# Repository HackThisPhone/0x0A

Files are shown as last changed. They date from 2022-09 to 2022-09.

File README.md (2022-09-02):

# 0x0A
The 0x0A Smartphone is an open-source, open-hardware smartphone. Repairable, customizable, and fully yours, the 0x0A phone gives the power back to you! 

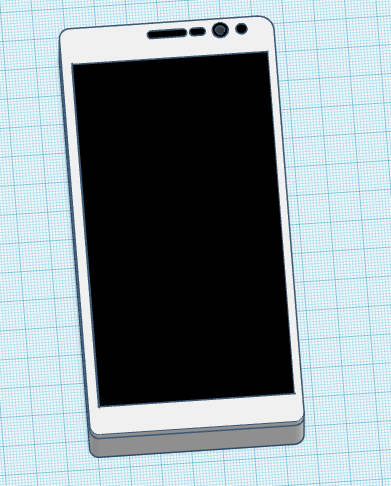
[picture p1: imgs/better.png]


## Features:

- Qualcomm Octa-Core ARM Cortex A-53 64-bit CPU @ 1.8GHz (2x quad-core with 512KB L2 cache)
- Adreno 506 GPU
- 16GB eMMC + 2GB LPDDR3
- 8,000mAh LiPo battery
- HD 720x1280 LCD with 16.7M color depth
- 10MP front & rear cameras
- 5G/4G/LTE/WCDMA
- WiFi 802.11a/b/g/n/ac
- Bluetooth 4.2/3.0/2.1
- GPS/BeiDou/GLONASS
- USB-C 3.0
- Dual SIM Standby
- 3D Printed Modular Case Design
- Full Schematics, BOM, & Supplier Info (self-serve on github)
- Android 9/10 Support
- Linux Support Planned (alternative operating systems welcomed here)

### Supported Carriers:

- North America    
  - Verizon
  - AT&T
  - T-Mobile
  - Sprint

Estimated BOM Cost: <$300
MSRP: $750

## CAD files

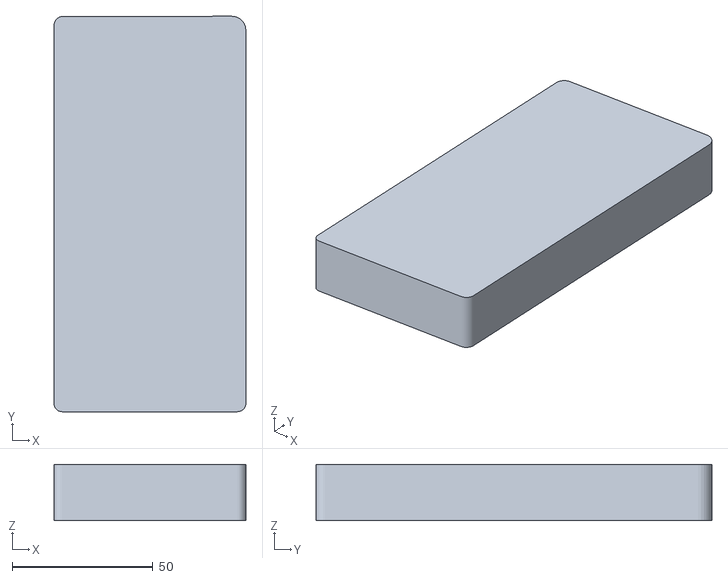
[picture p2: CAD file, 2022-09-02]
src/models/body.obj
68.3 x 140.7 x 20.0

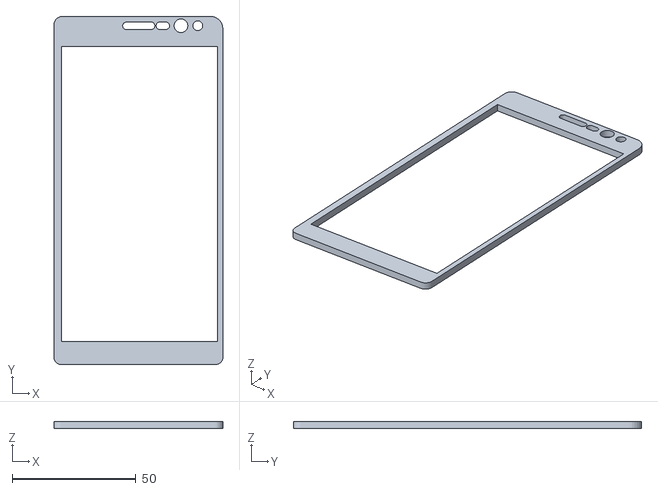
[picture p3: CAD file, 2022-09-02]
src/models/screen.obj
68.3 x 140.7 x 2.87

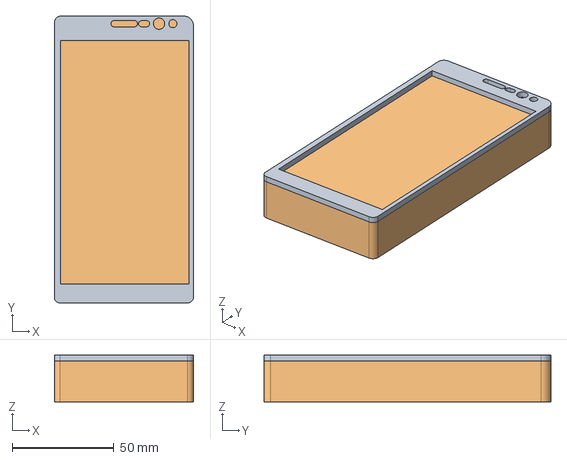
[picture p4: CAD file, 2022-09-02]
src/models/phone.FCStd
68.3 x 140.7 x 22.9 mm

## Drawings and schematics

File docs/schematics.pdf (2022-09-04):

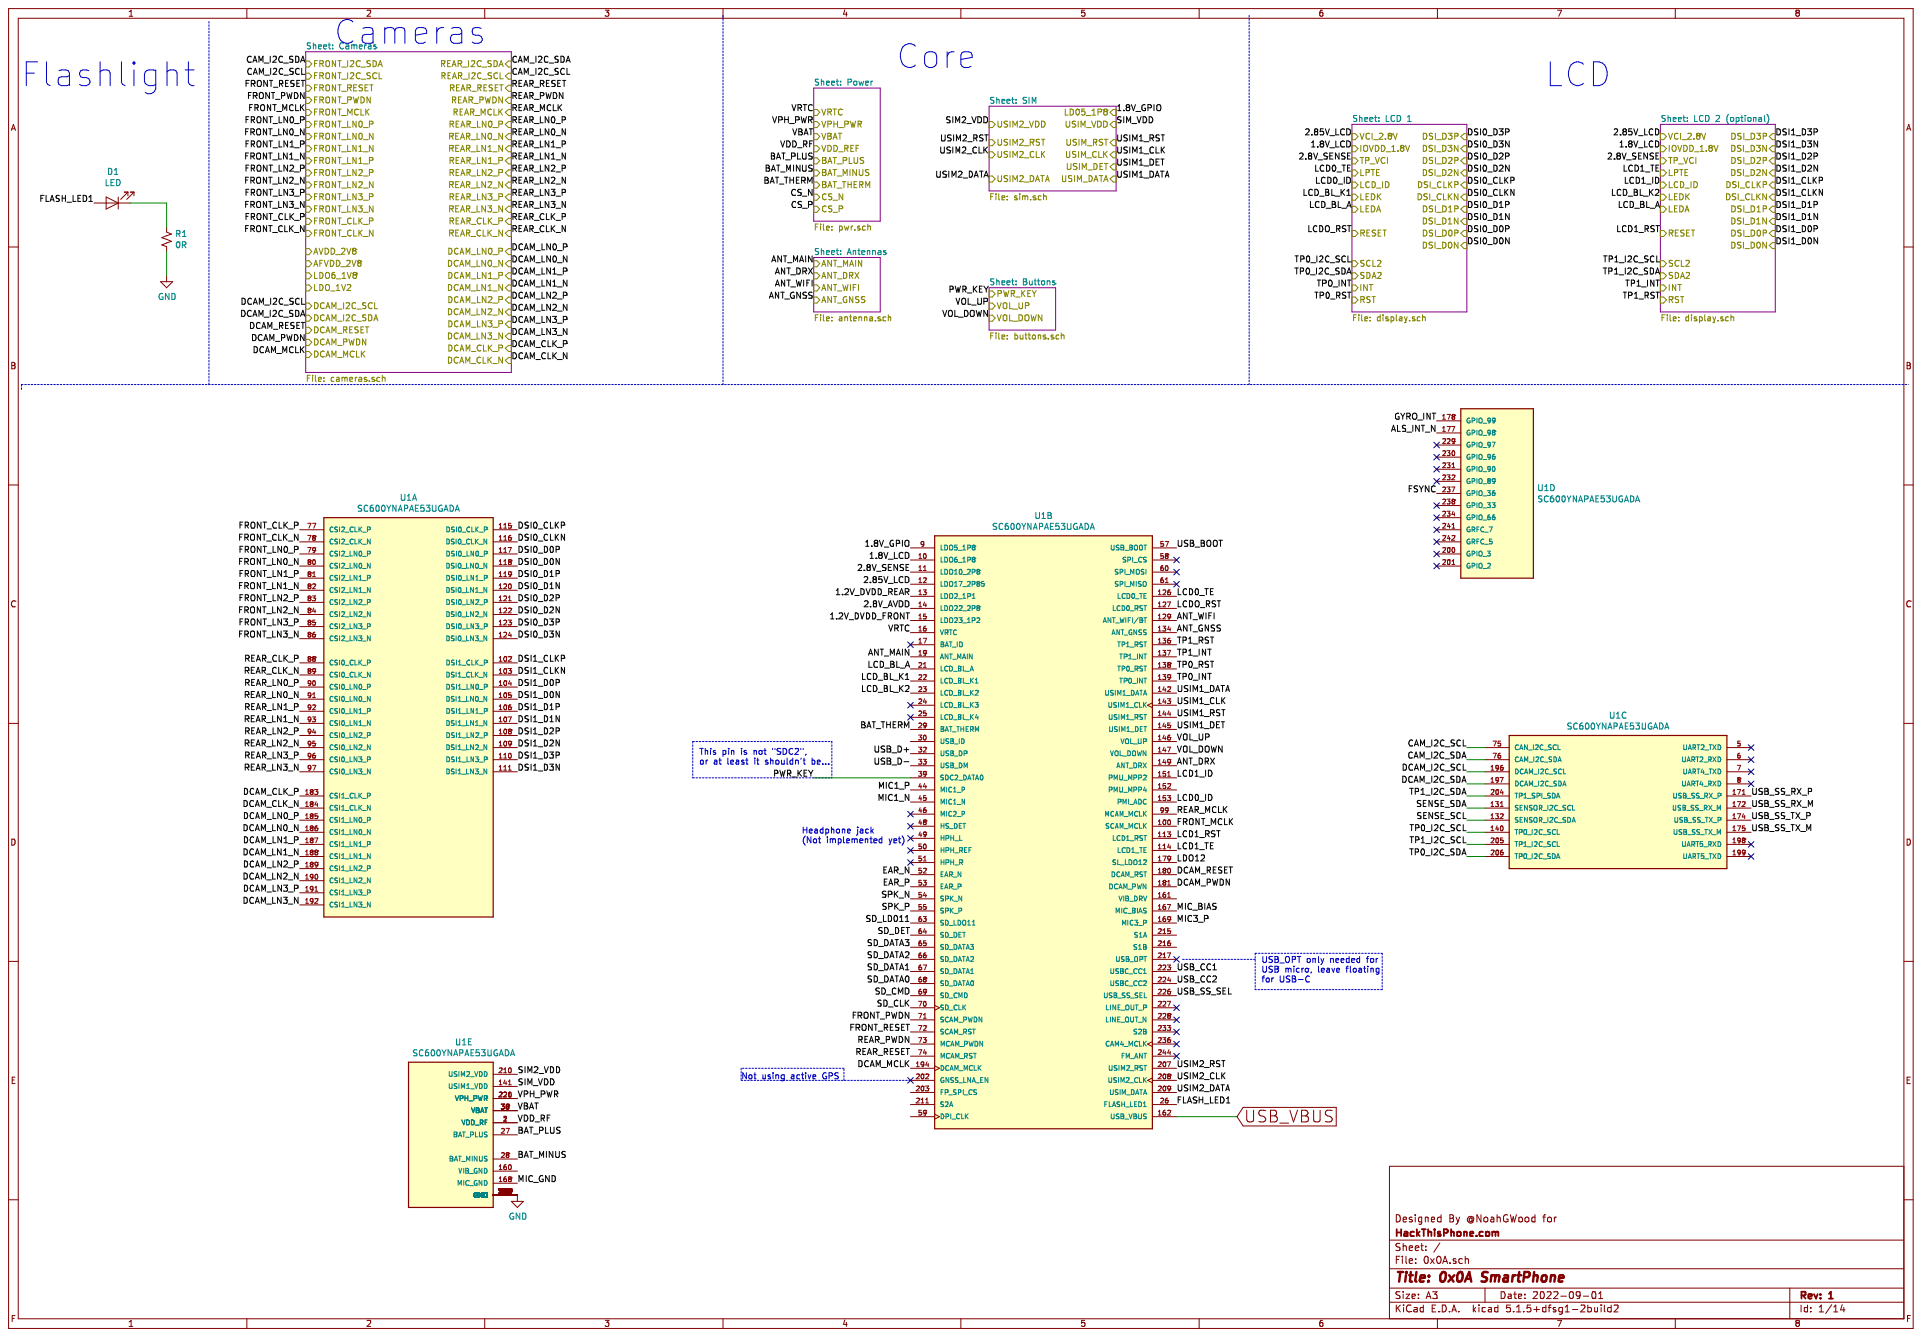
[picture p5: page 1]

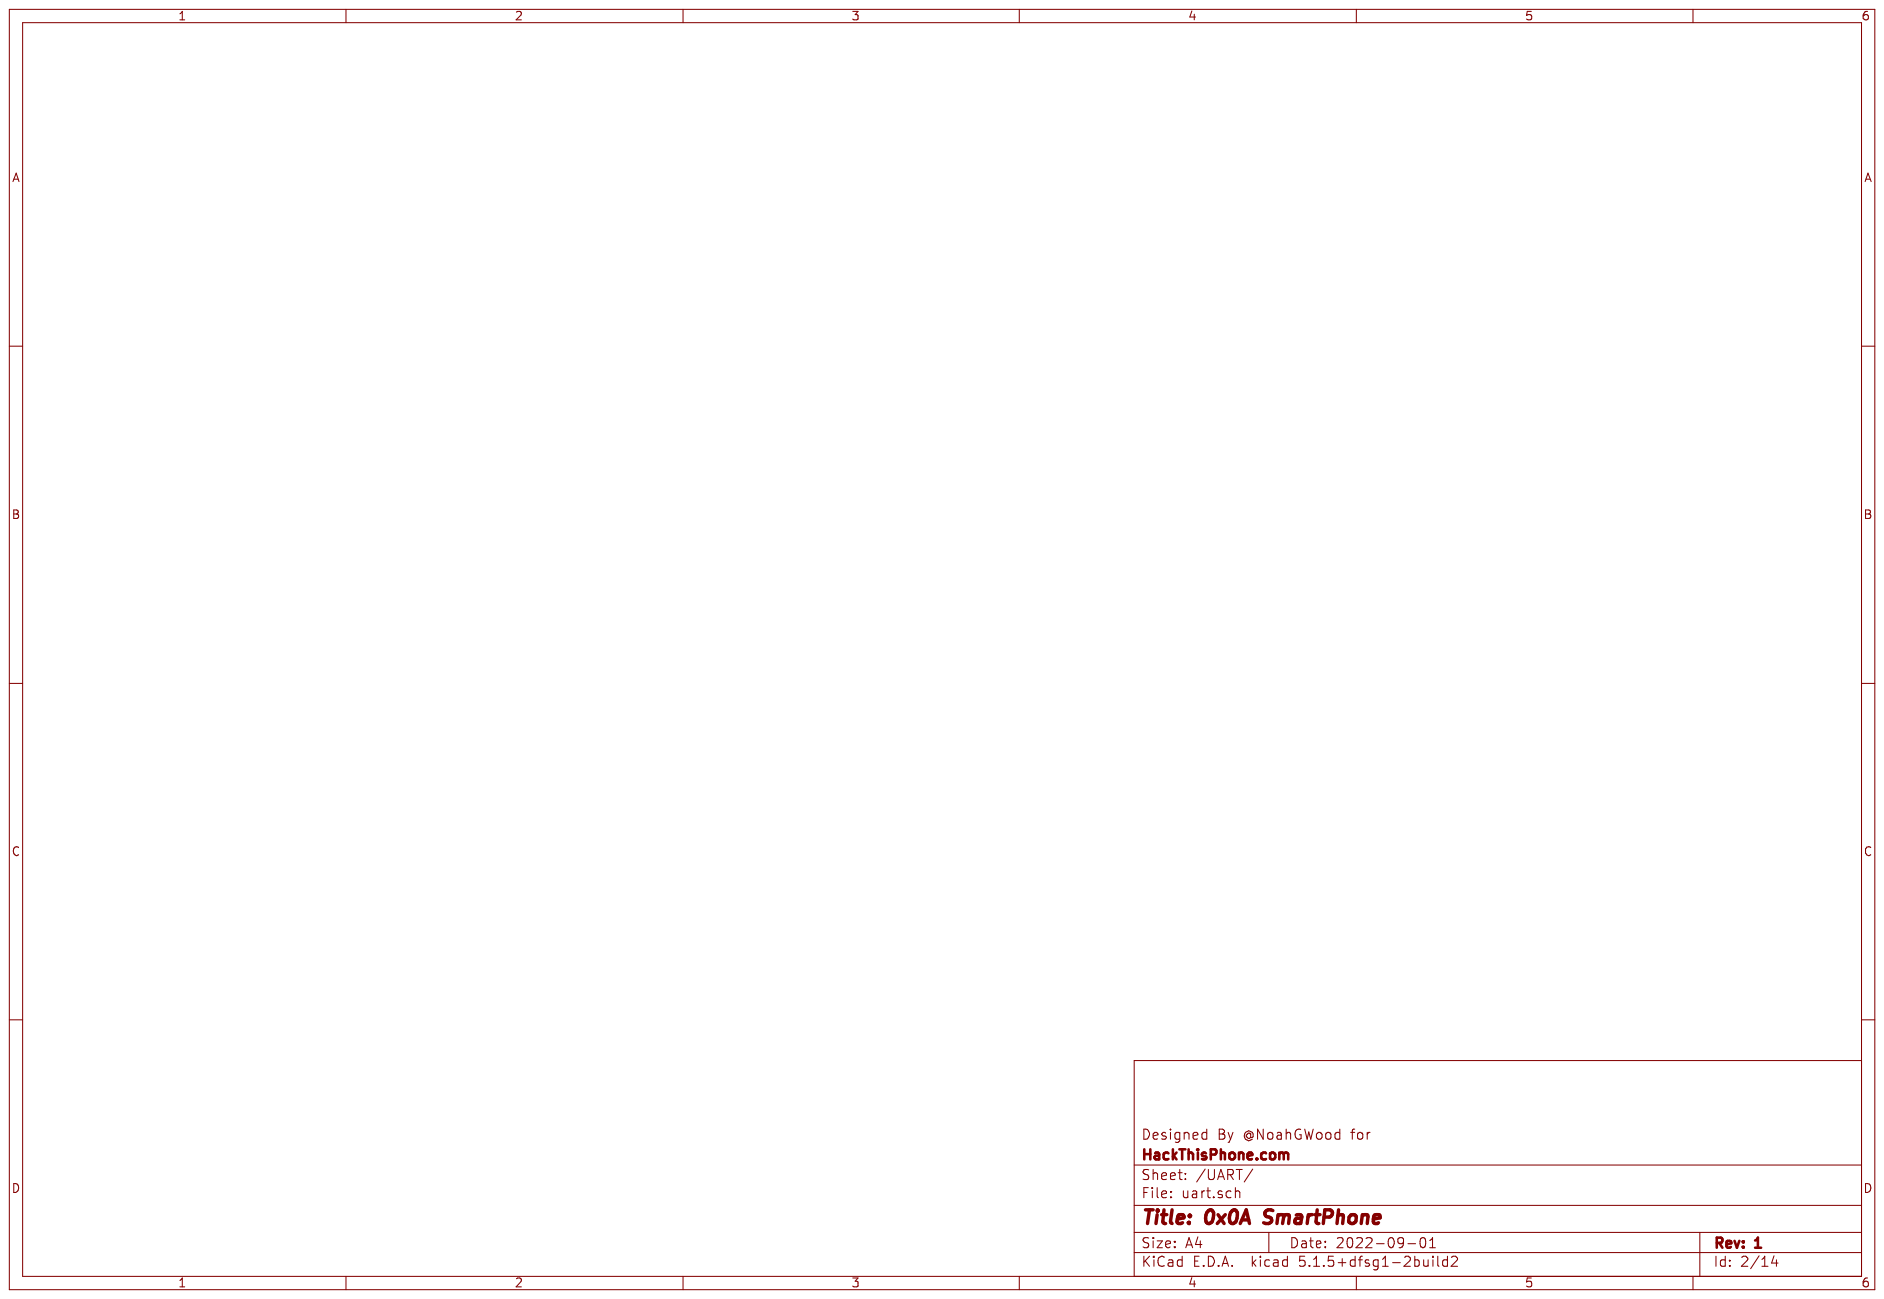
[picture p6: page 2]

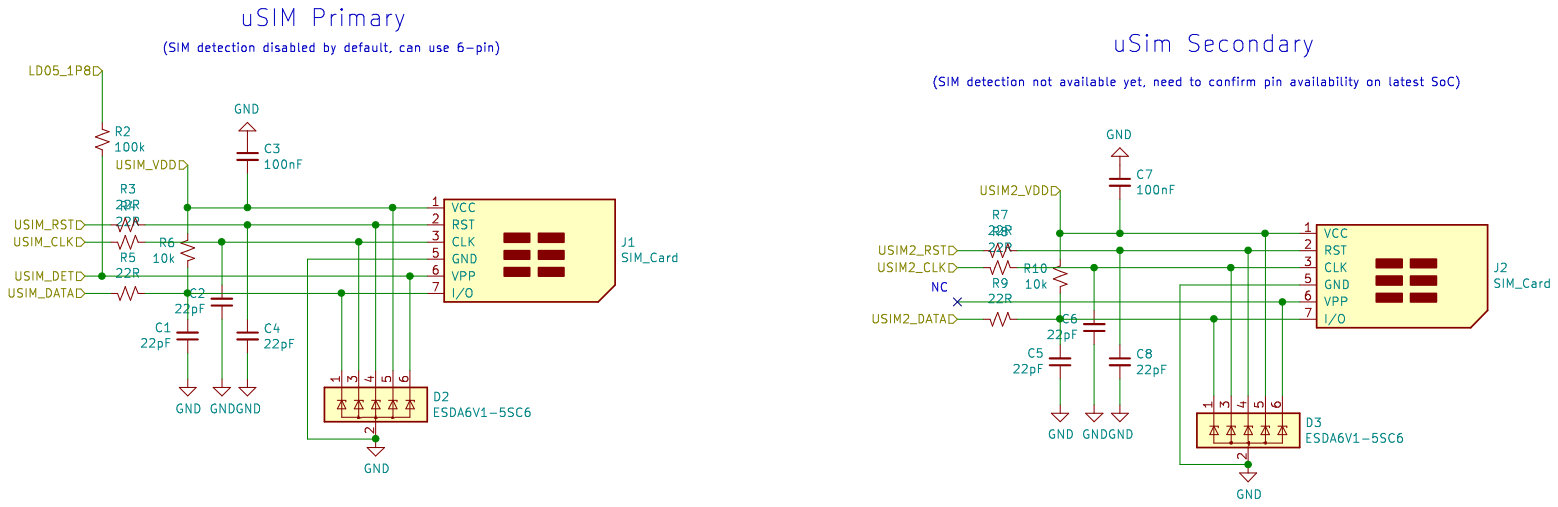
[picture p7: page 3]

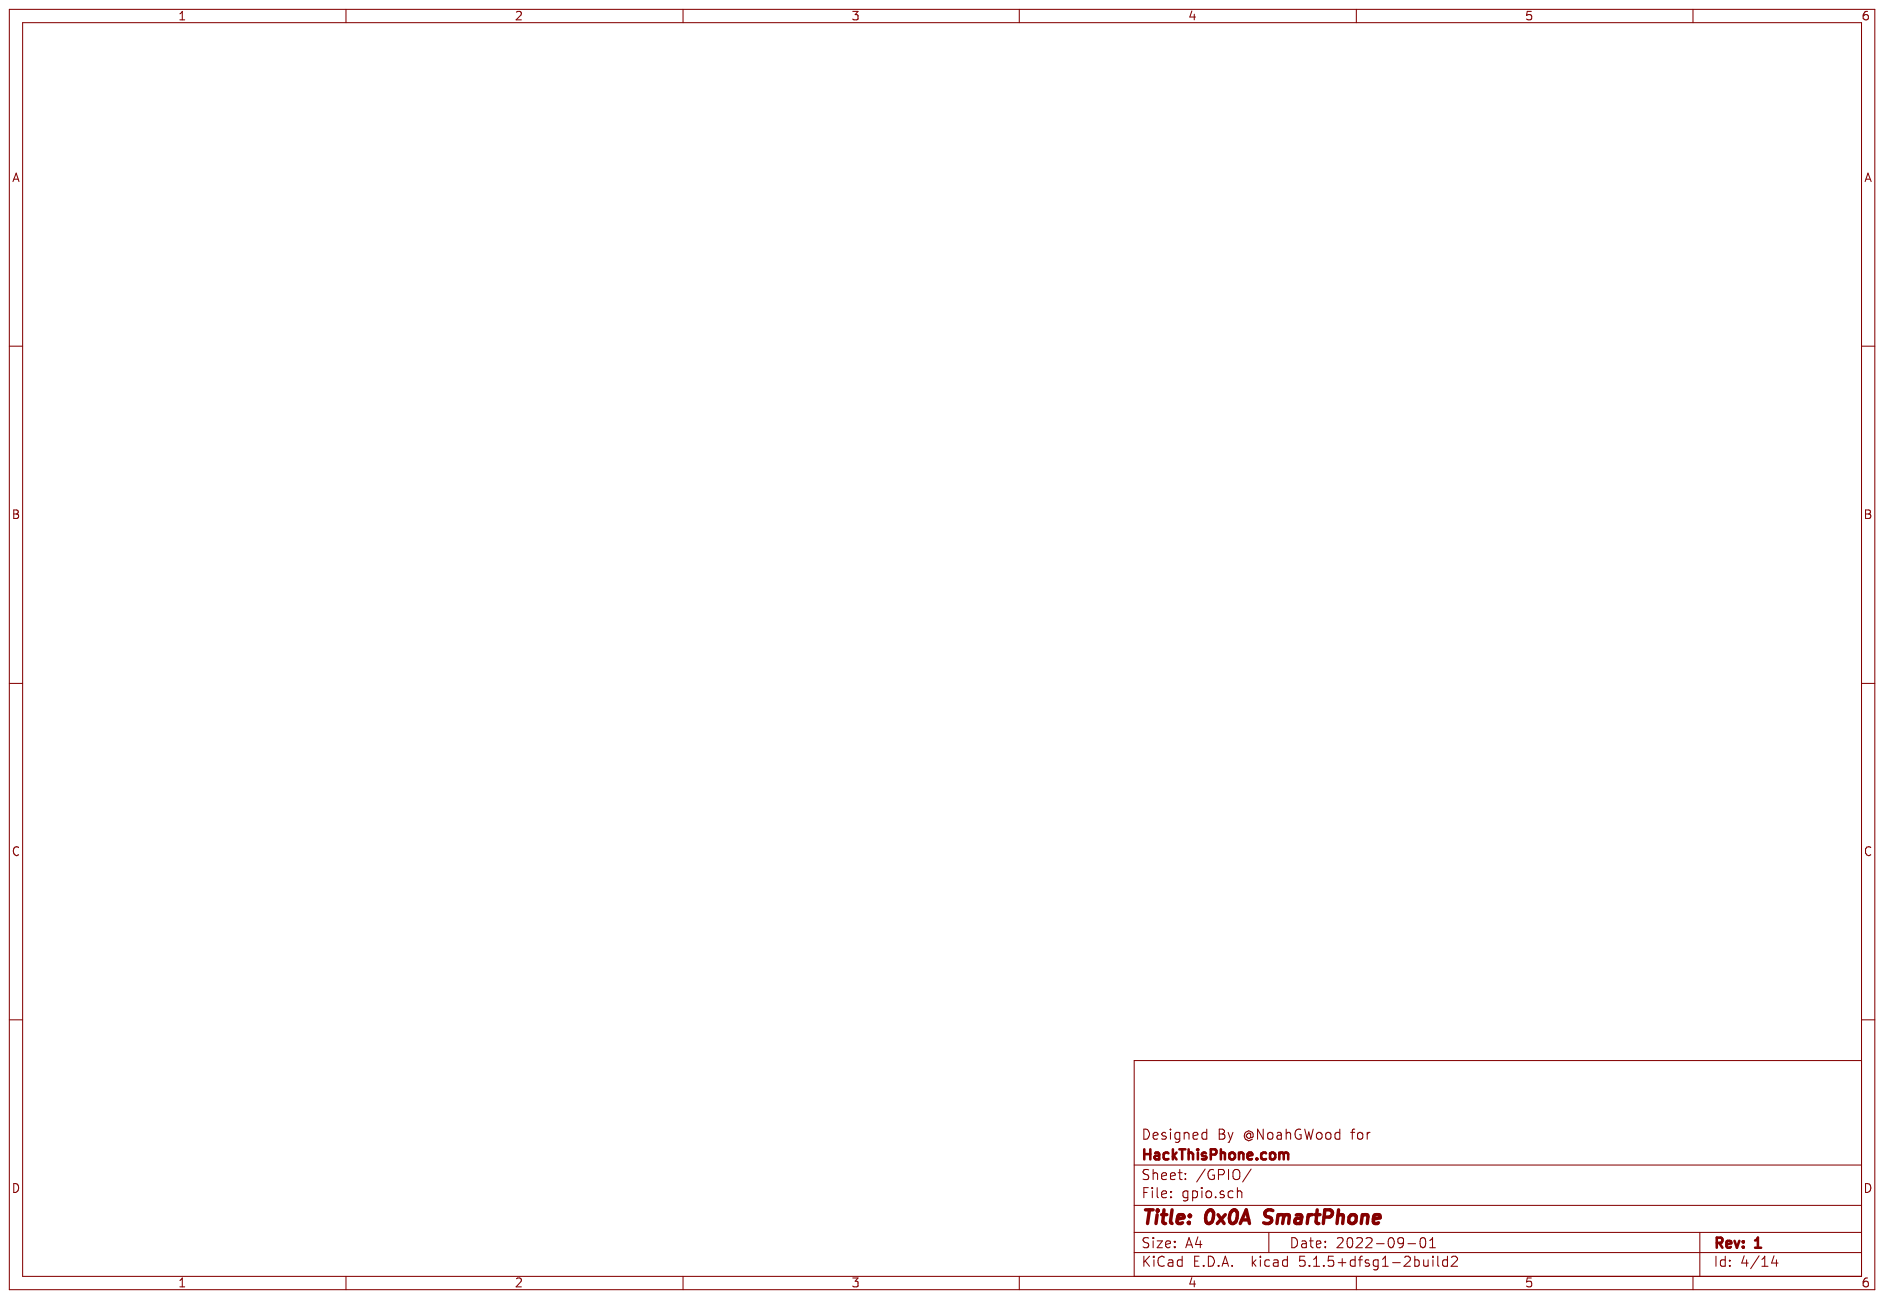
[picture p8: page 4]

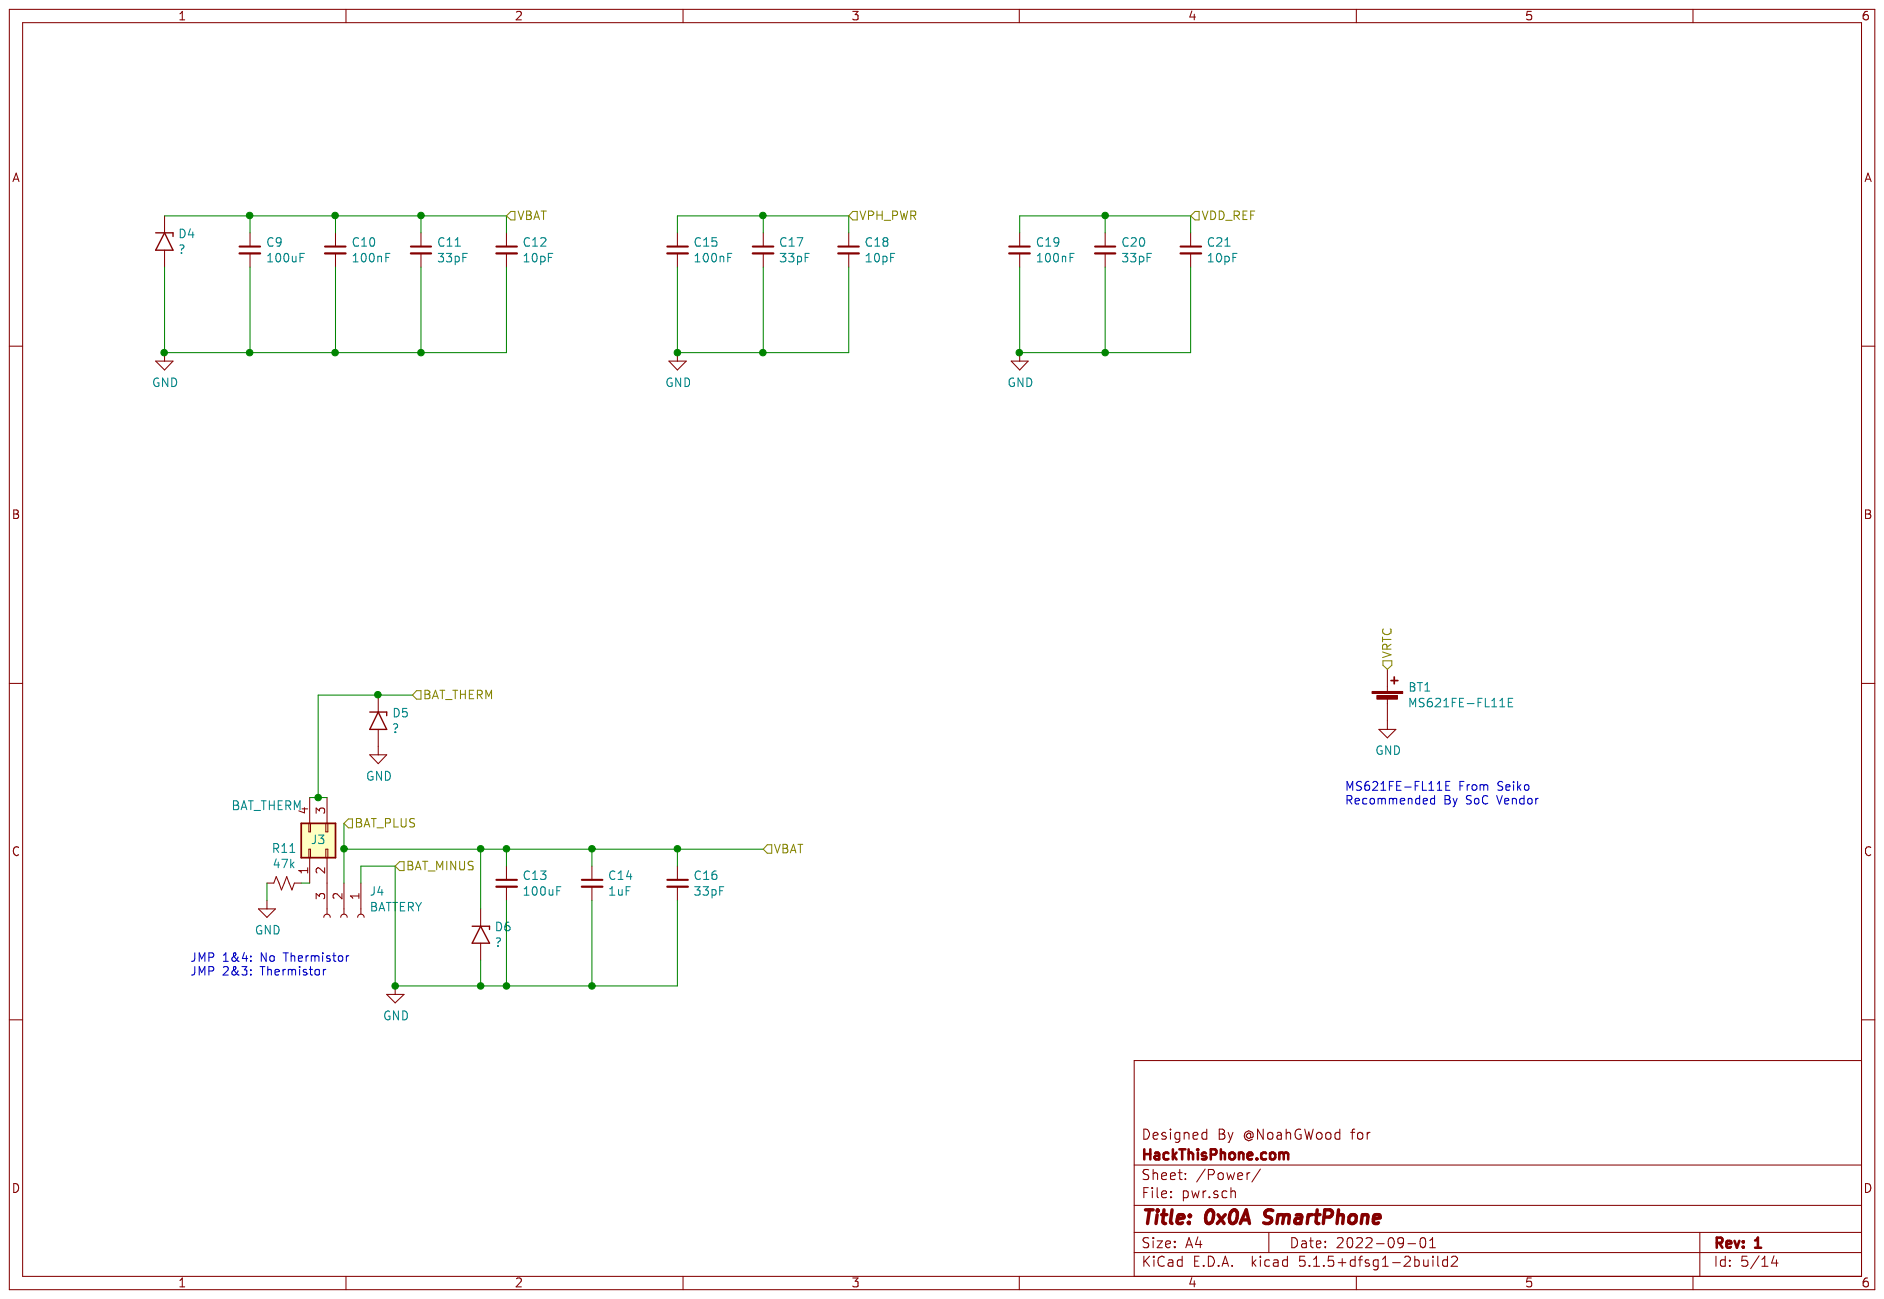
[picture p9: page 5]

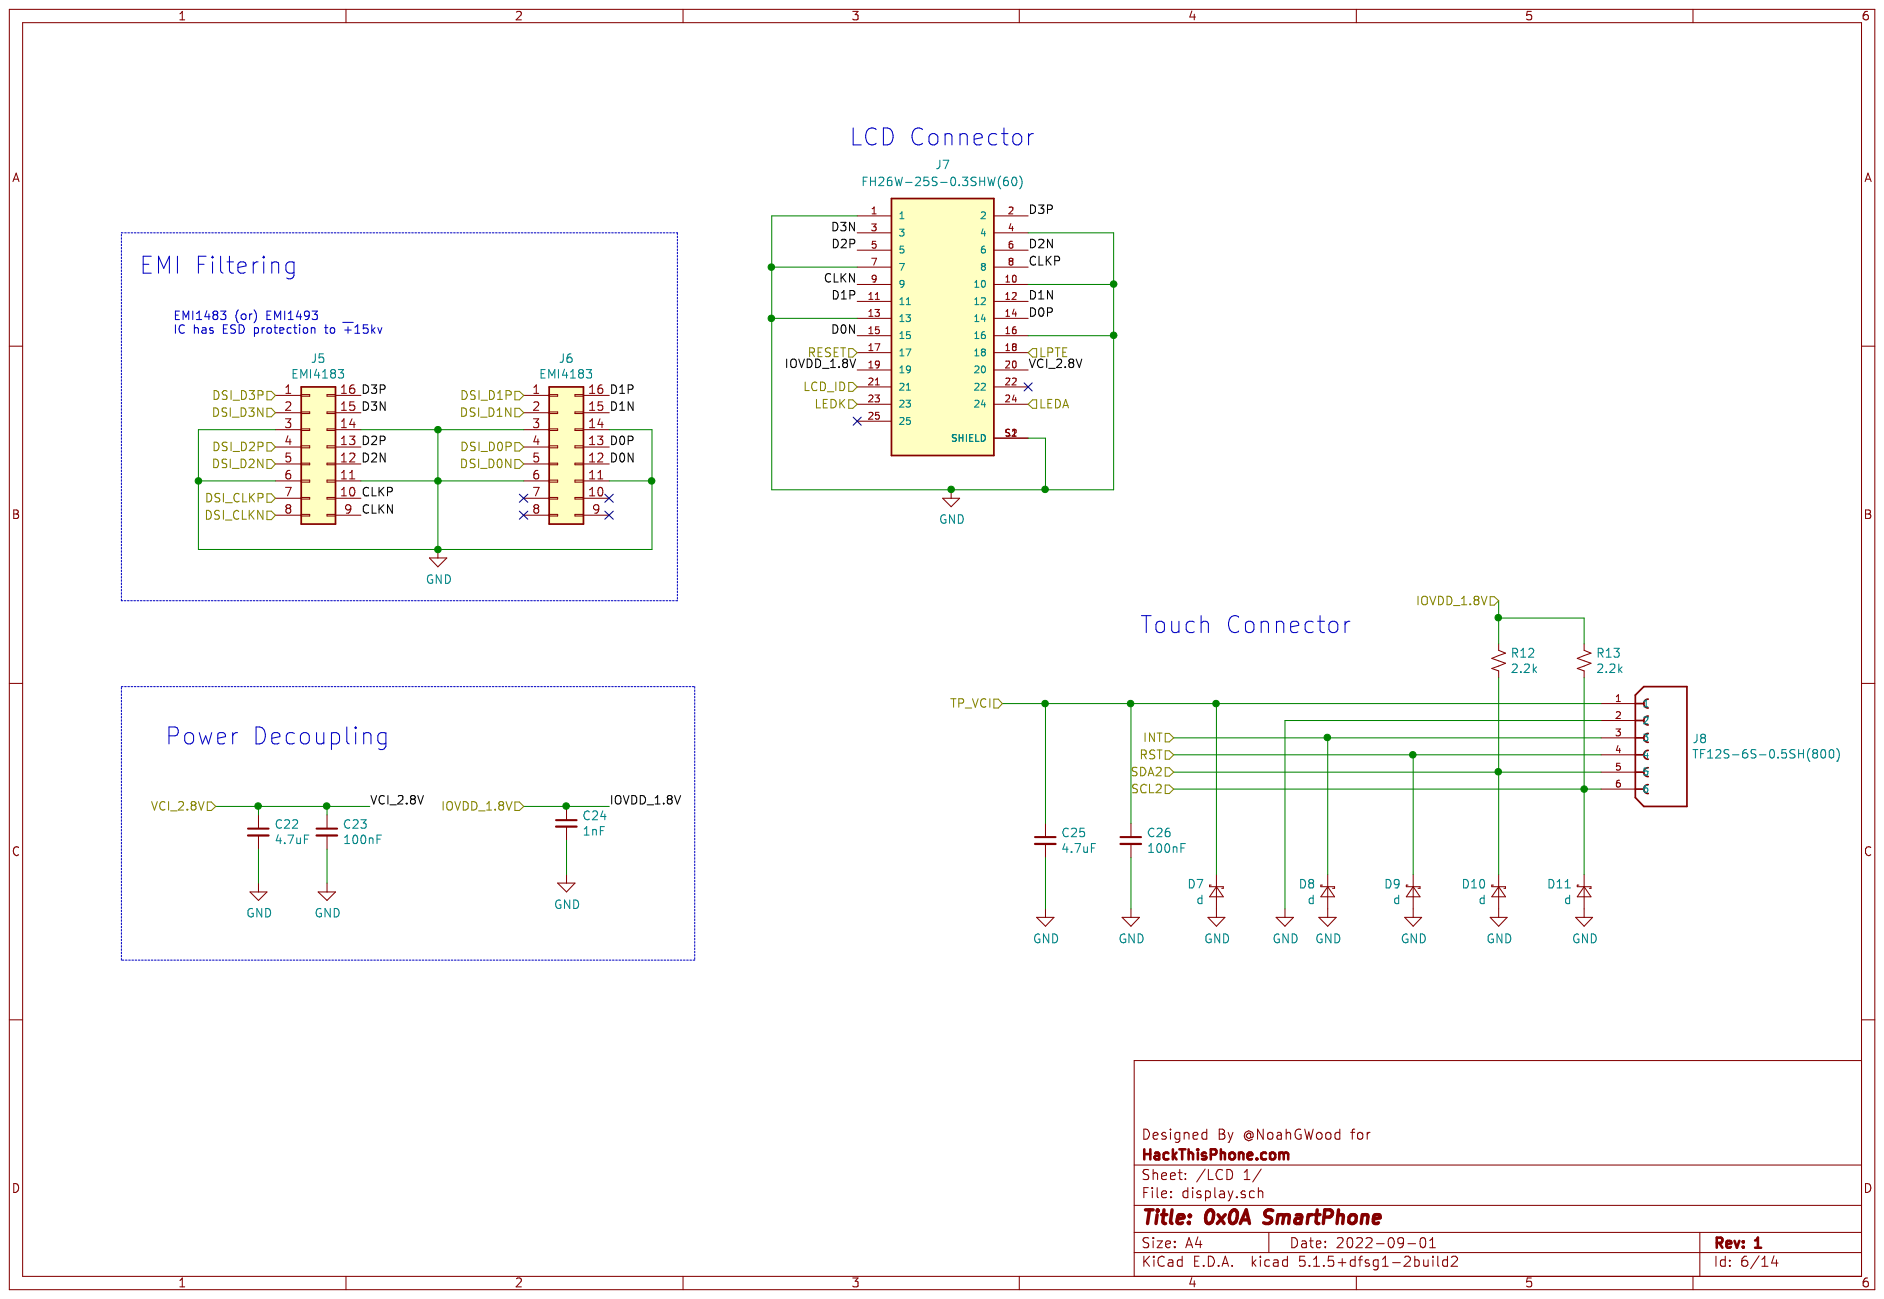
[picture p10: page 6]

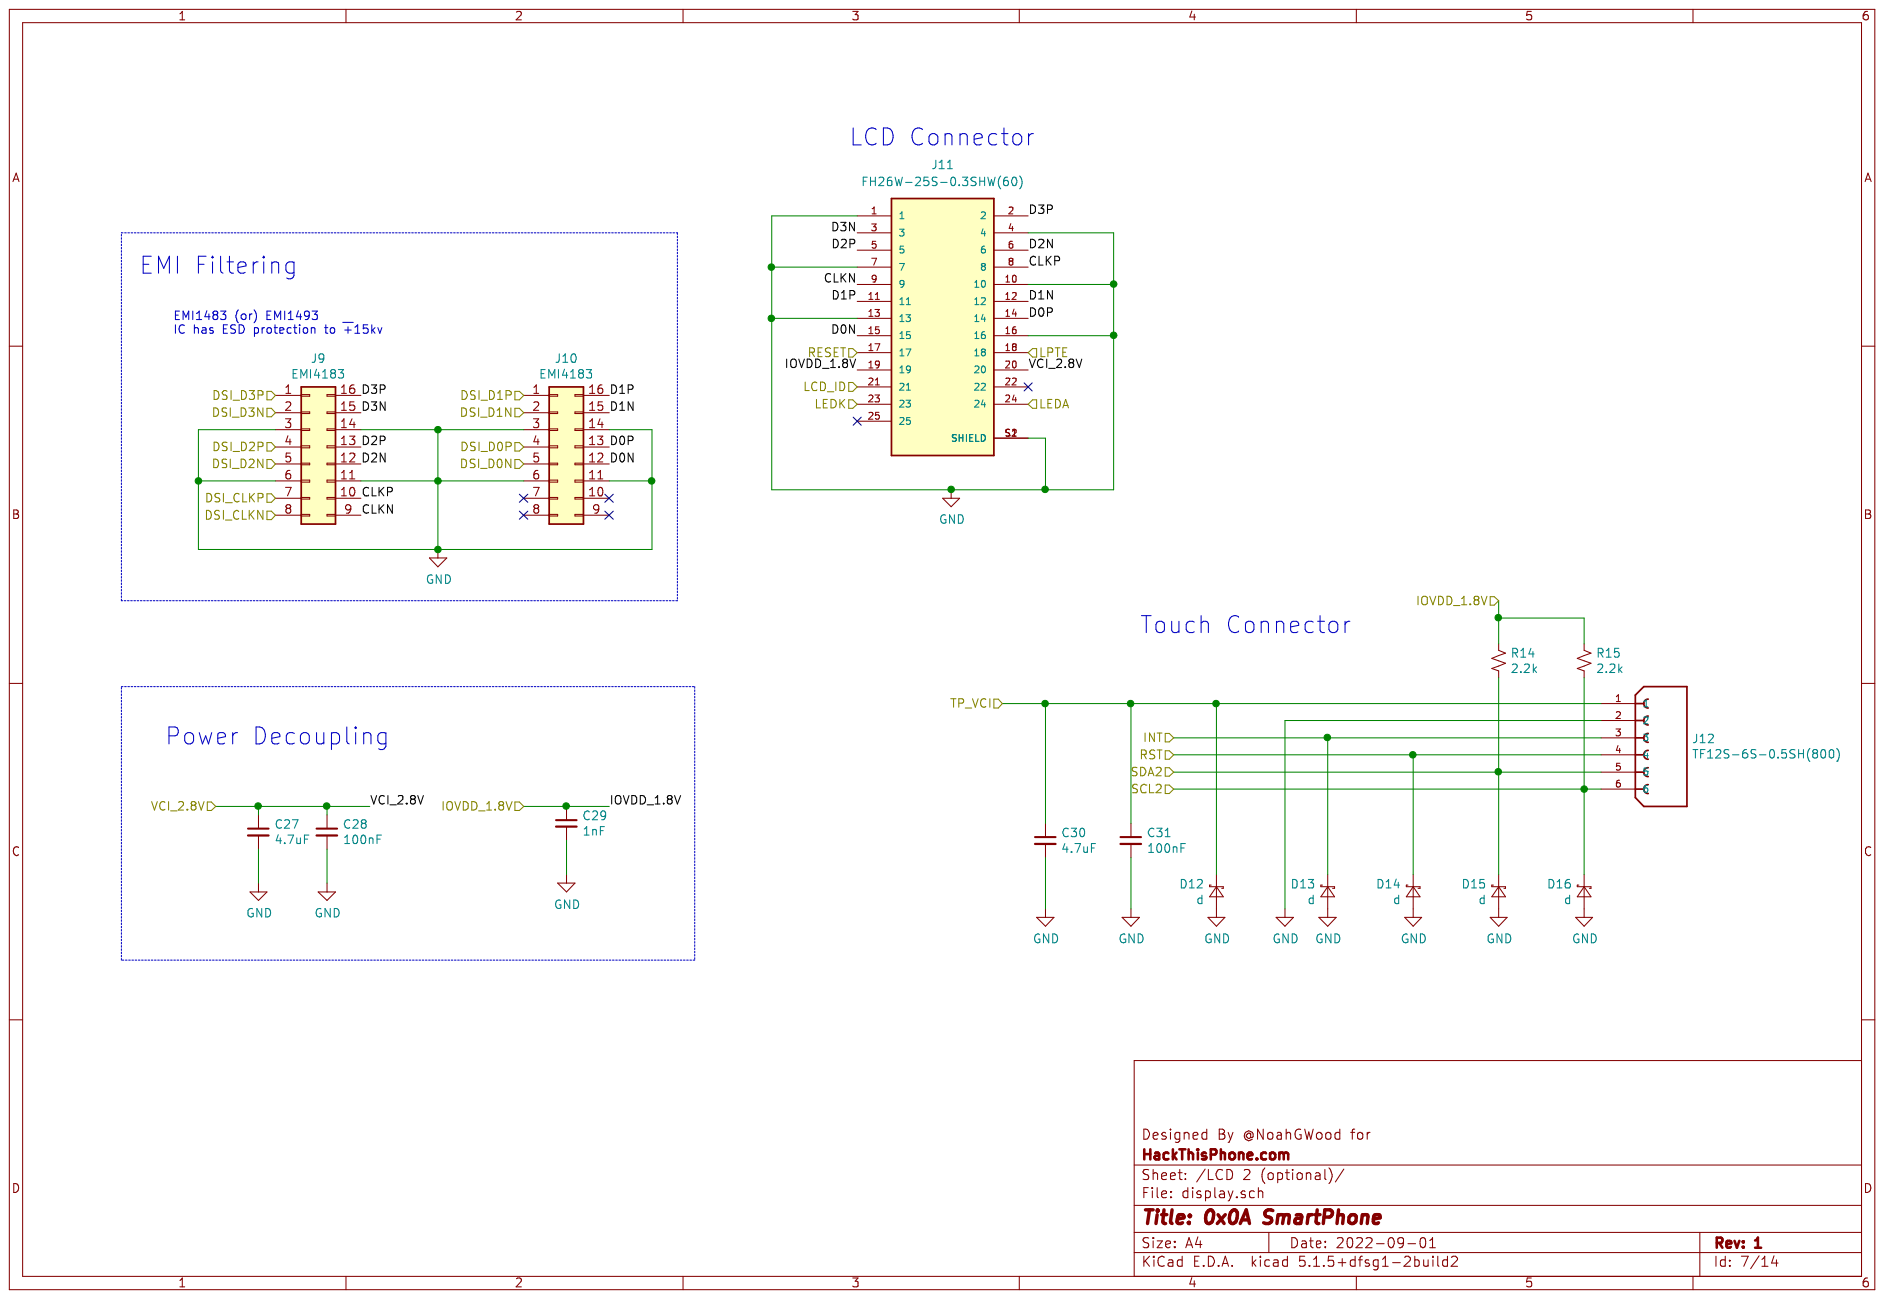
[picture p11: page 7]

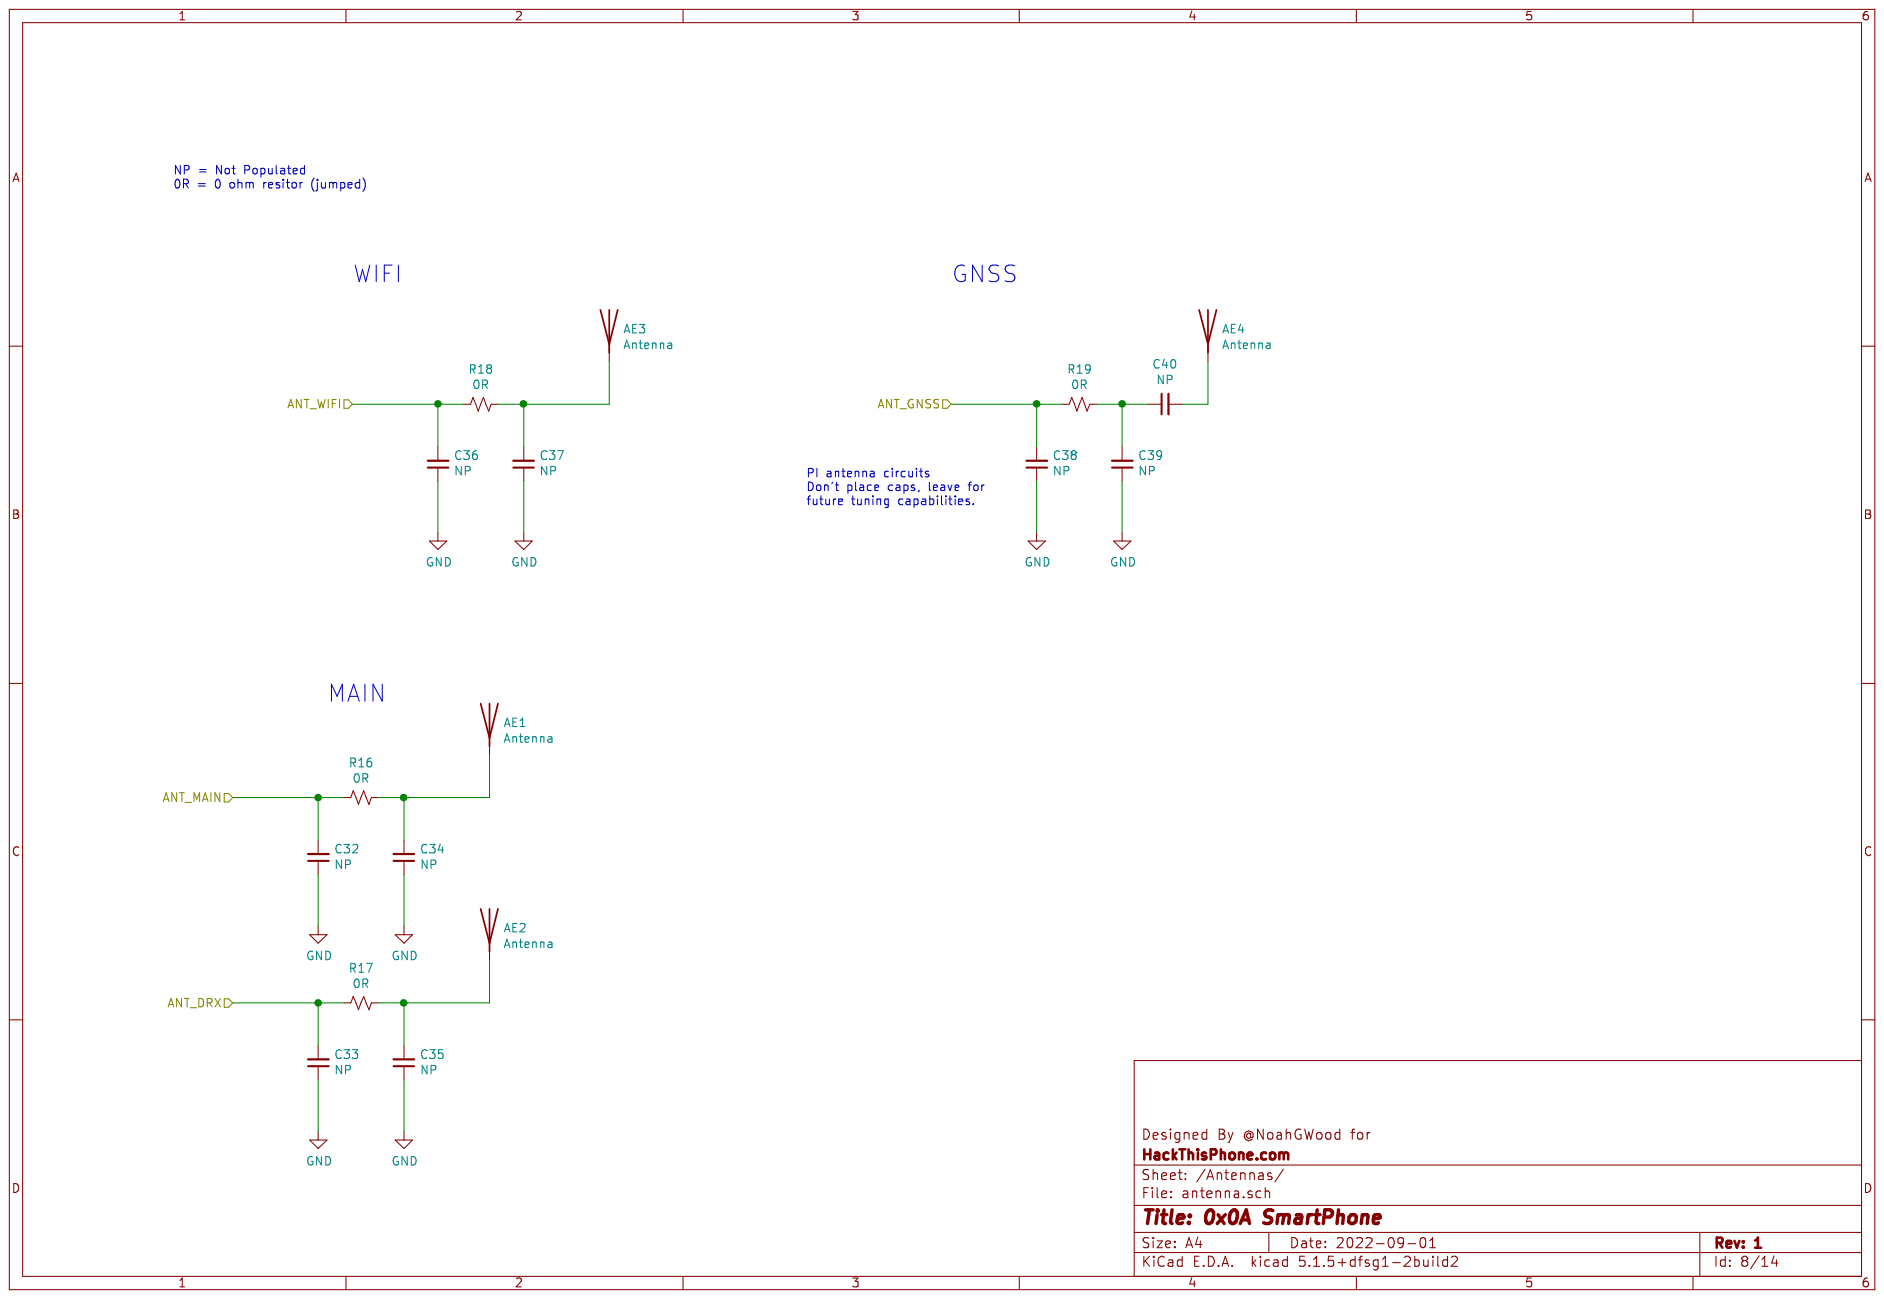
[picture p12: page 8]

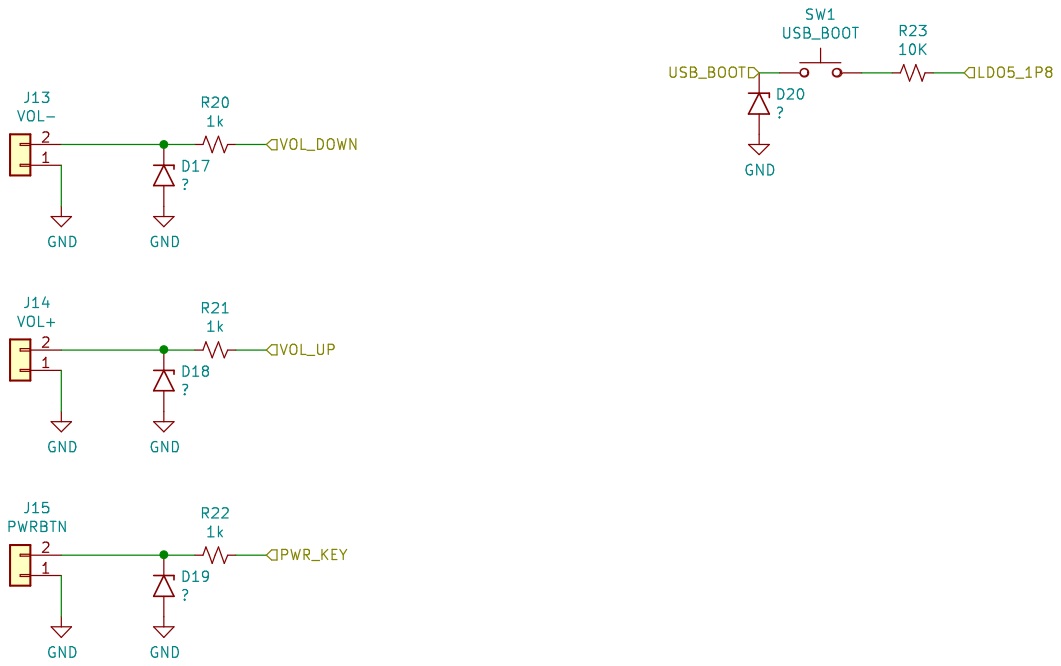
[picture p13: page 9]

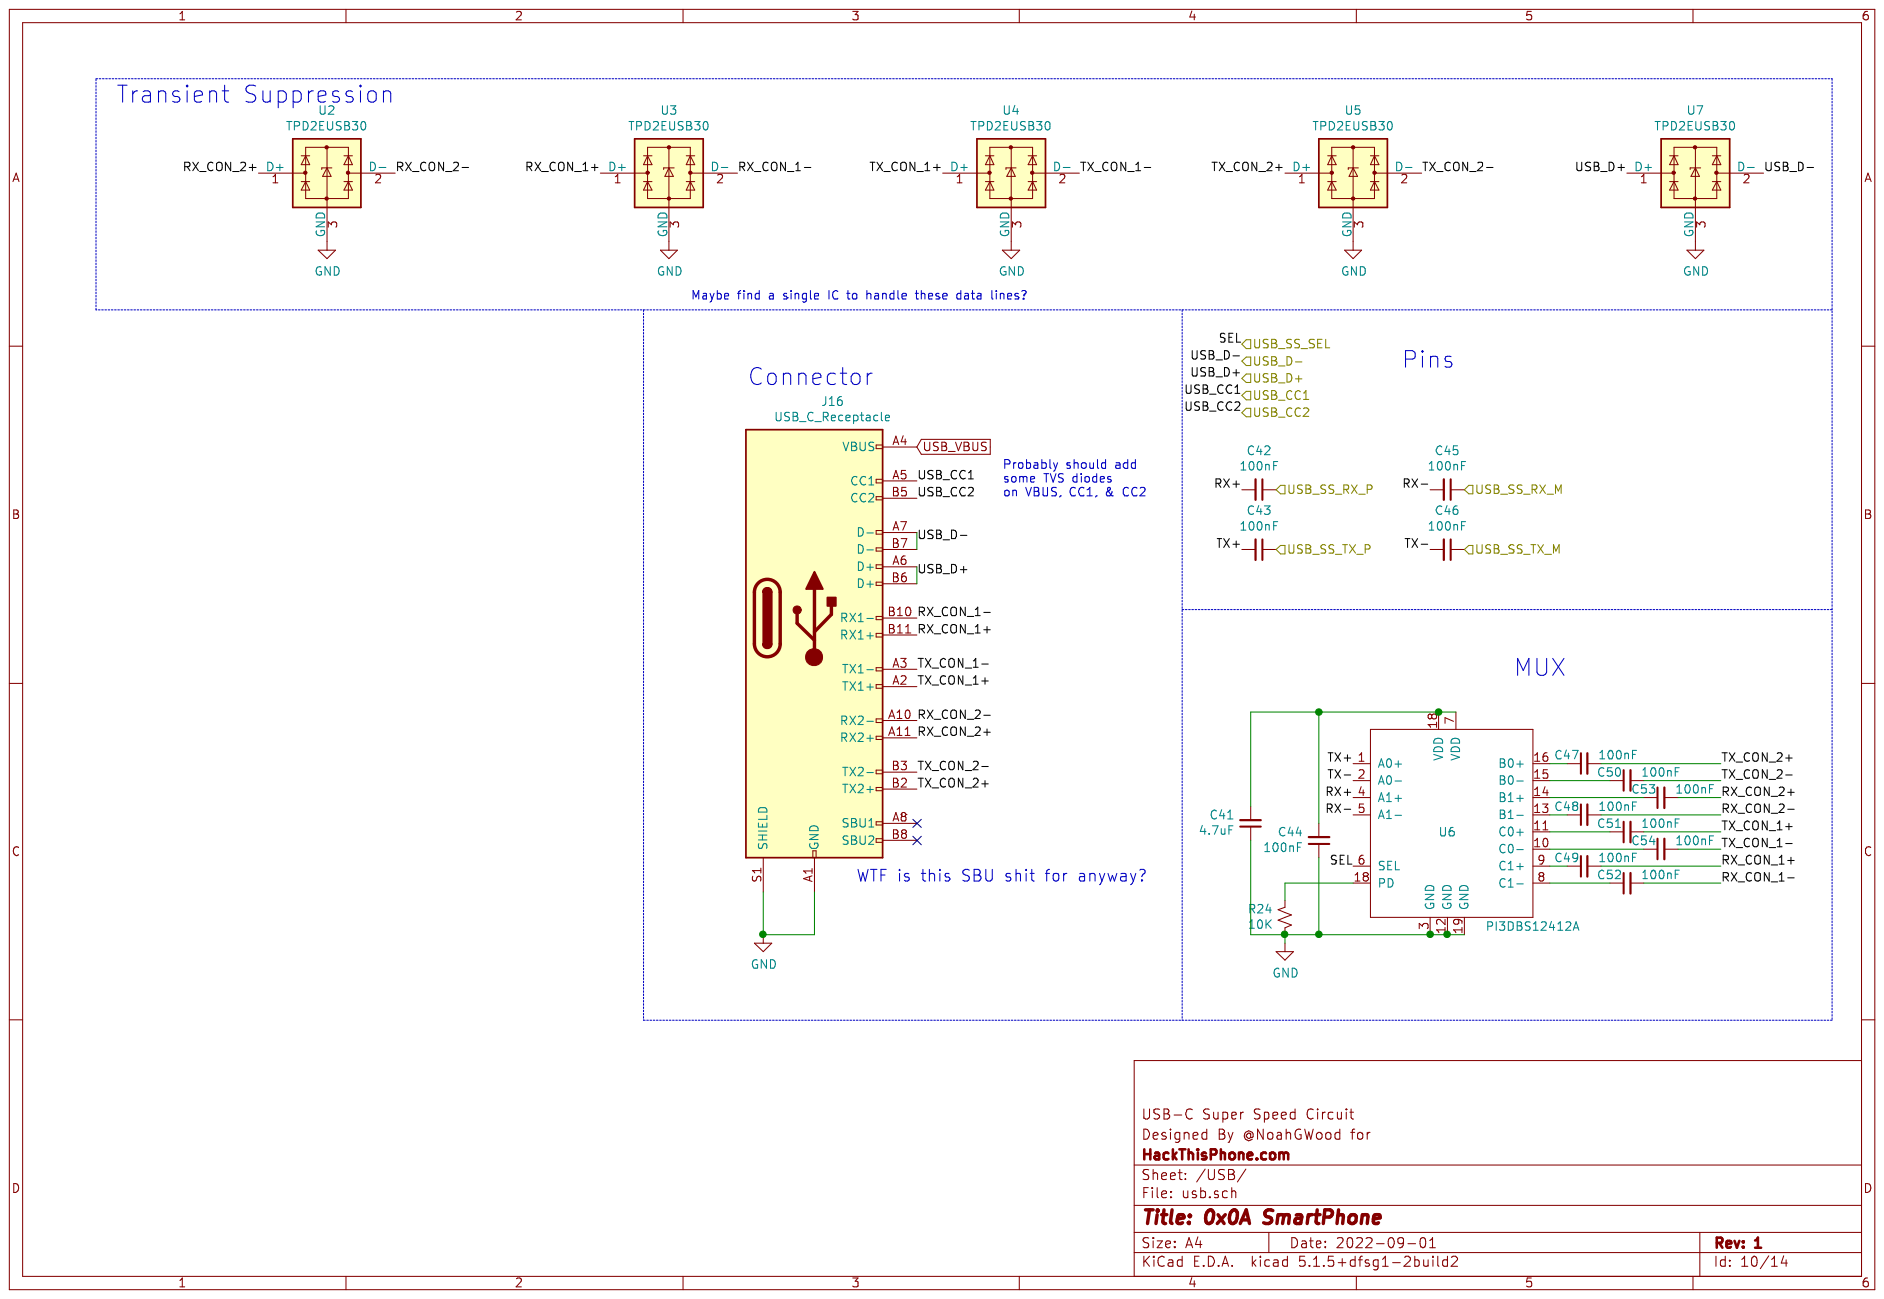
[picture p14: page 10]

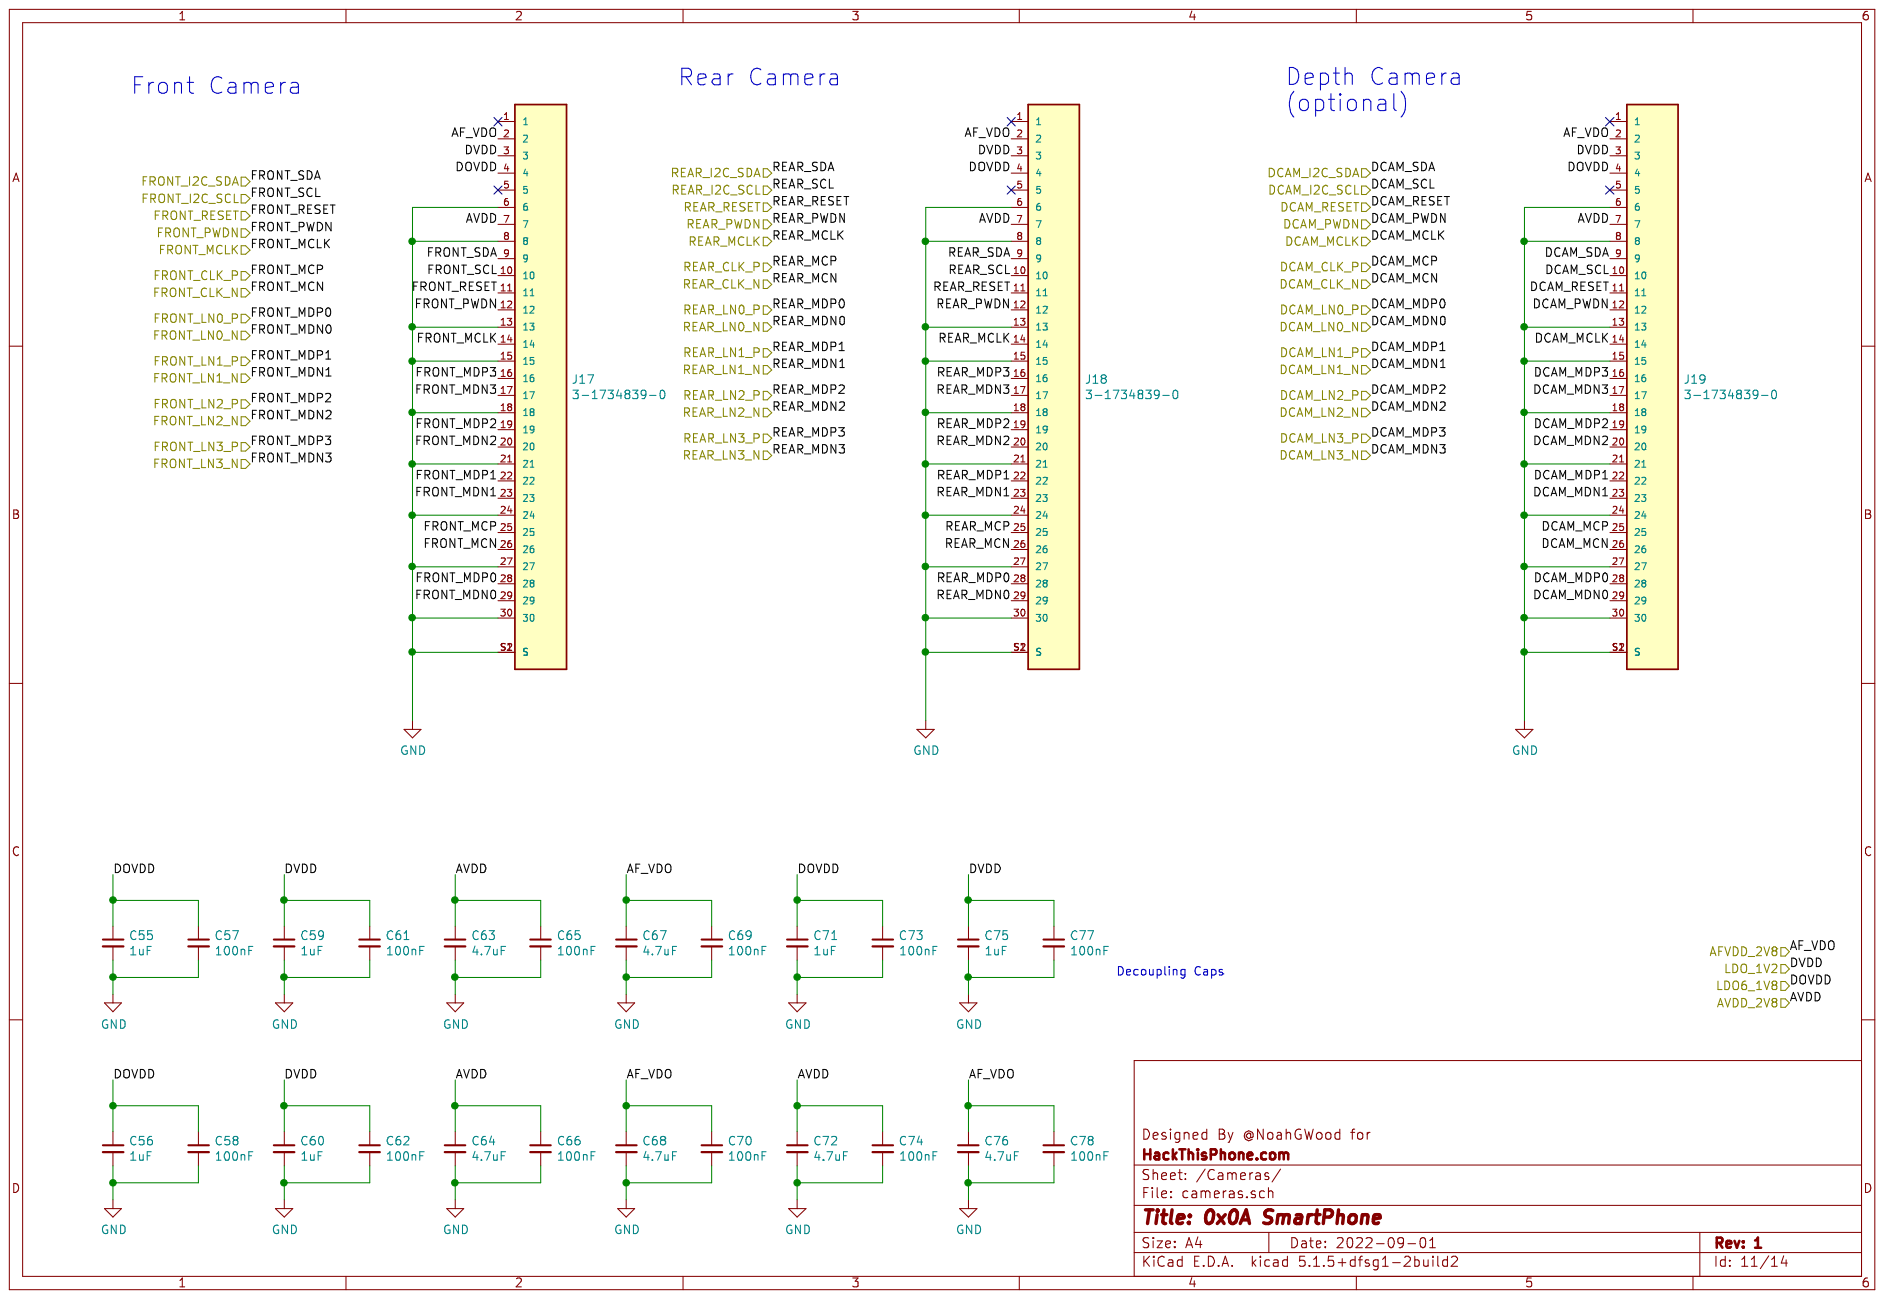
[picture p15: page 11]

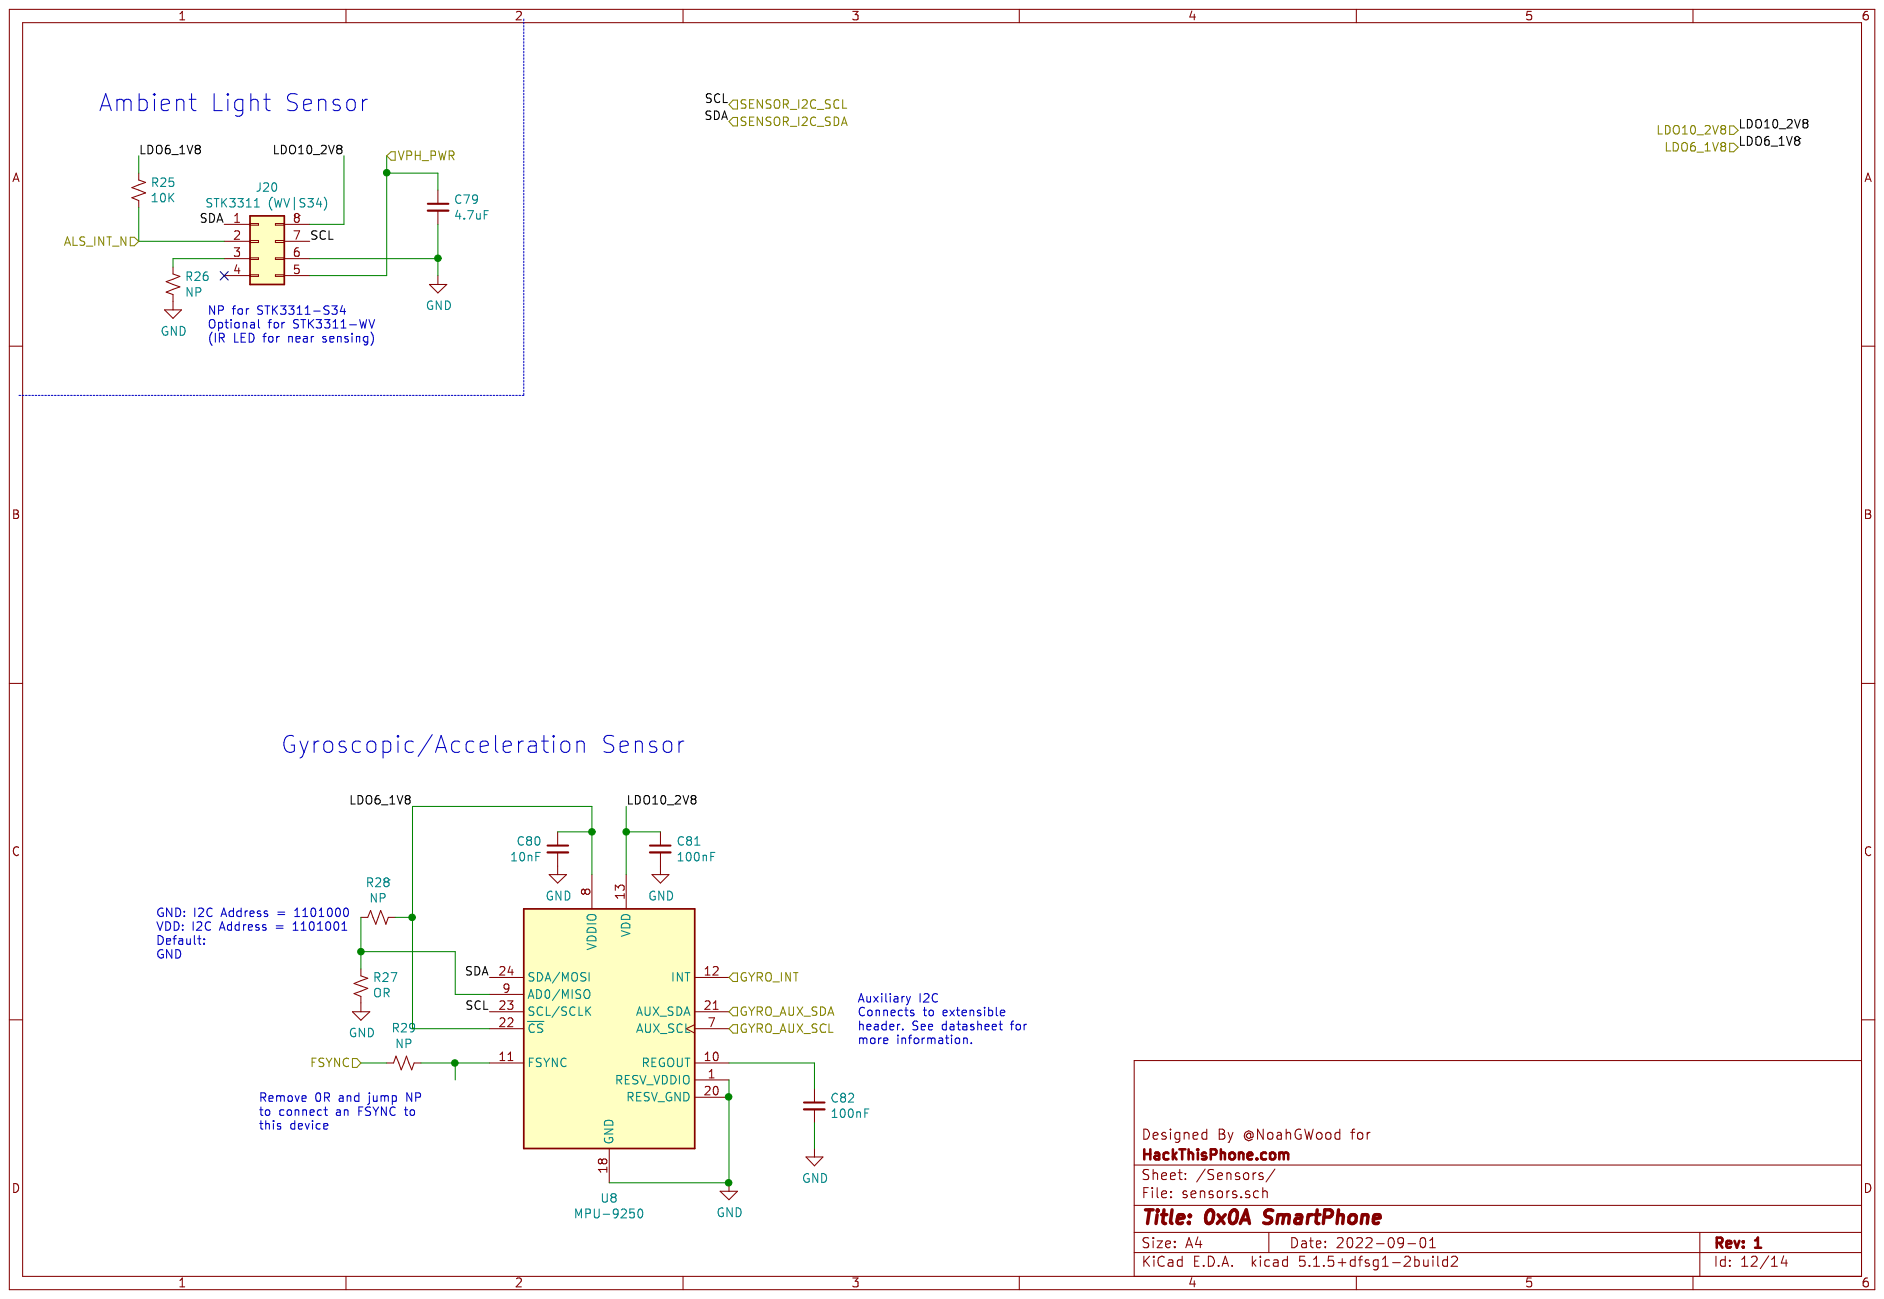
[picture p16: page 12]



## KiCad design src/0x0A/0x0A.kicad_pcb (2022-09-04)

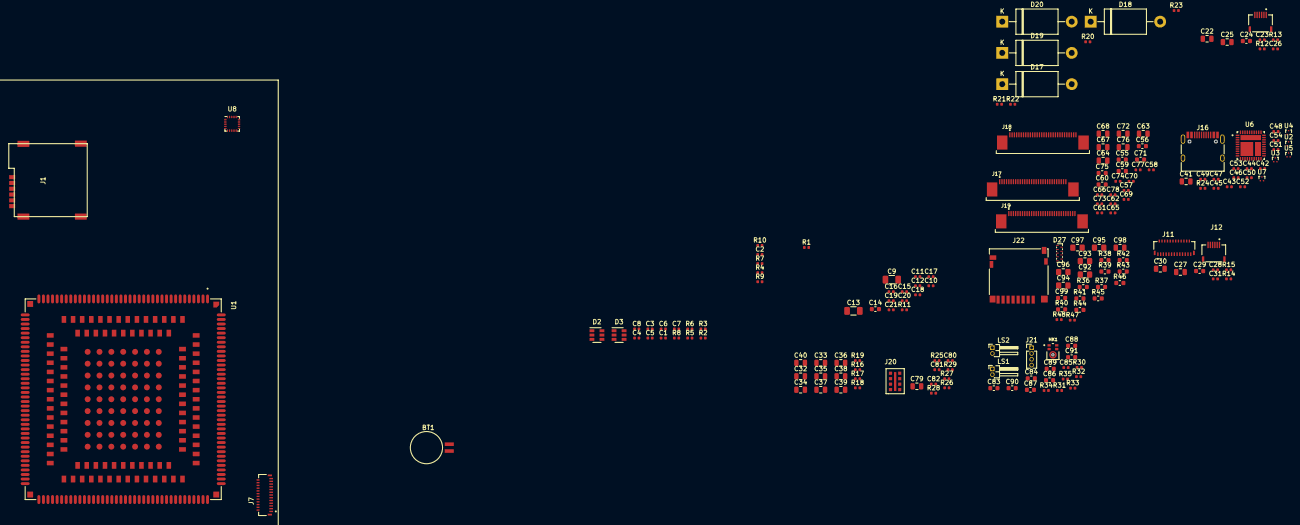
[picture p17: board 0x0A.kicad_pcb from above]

Board: 2 copper layers, 179 parts (1 on the bottom side), 135 nets, no tracks yet.

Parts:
BT1: MS621FE-FL11E; BatteryHolder_Seiko_MS621F
C1, C2, C4, C5, C6, C8: 22pF; C_0402_1005Metric
C3, C7, C10, C15, C19, C23, C26, C28, C31, C42, C43, C44, C45, C46, C47, C48, C49, C50, C51, C52, C53, C54, C57, C58, C61, C62, C65, C66, C69, C70, C73, C74, C77, C78, C81, C82, C85: 100nF; C_0402_1005Metric
C9, C13: 100uF; C_1206_3216Metric
C11, C16, C17, C20: 33pF; C_0402_1005Metric
C12, C18, C21: 10pF; C_0402_1005Metric
C14, C55, C56, C59, C60, C71, C75: 1uF; C_0603_1608Metric
C22, C25, C27, C30, C41, C63, C64, C67, C68, C72, C76, C79, C98: 4.7uF; C_0805_2012Metric
C24, C29: 1nF; C_0603_1608Metric
C32, C33, C34, C35, C36, C37, C38, C39, C40: NP; C_0805_2012Metric
C80: 10nF; C_0402_1005Metric
C83, C84, C86, C87, C88, C89, C91, C99: 33pF; C_0603_1608Metric
C90: 100pF; C_0603_1608Metric
C92, C93, C94, C95, C96, C97: NP_27pF; C_0805_2012Metric_Pad1.15x1.40mm_HandSolder
D2, D3: ESDA6V1-5SC6; SOT-23-6
D17, D18, D19, D20: ?; D_DO-201AE_P15.24mm_Horizontal
D27: WE-TVS-824014881; UDFN-9_1.0x3.8mm_P0.5mm
J1, J2: SIM_Card; SIM-002-P6
J7, J11: FH26W-25S-0.3SHW(60); HRS_FH26W-25S-0.3SHW(60)
J8, J12: TF12S-6S-0.5SH(800); HRS_TF12S-6S-0.5SH(800)
J16: USB_C_Receptacle; USB_C_Receptacle_HRO_TYPE-C-31-M-12
J17, J18, J19: 3-1734839-0; TE_3-1734839-0
J20: STK3311 (WV|S34); STK3311
J21: Conn_01x04; PinHeader_1x04_P1.27mm_Vertical
J22: Micro_SD_Card_Det; microSD_HC_Hirose_DM3D-SF
LS1, LS2: Speaker; PinHeader_1x02_P1.27mm_Horizontal
MK1: MP23ABS1TR; MIC_MP23ABS1TR
R1, R16, R17, R18, R19, R30, R31, R32, R33, R34, R35, R48: 0R; R_0402_1005Metric
R2: 100k; R_0402_1005Metric
R3, R4, R5, R7, R8, R9: 22R; R_0402_1005Metric
R6, R10: 10k; R_0402_1005Metric
R11: 47k; R_0402_1005Metric
R12, R13, R14, R15: 2.2k; R_0402_1005Metric
R20, R21, R22: 1k; R_0402_1005Metric
R23, R24, R25: 10K; R_0402_1005Metric
R26, R28, R29: NP; R_0402_1005Metric
R27: OR; R_0402_1005Metric
R36, R37, R38, R39, R40, R41: 33R; R_0603_1608Metric
R42, R43, R44, R45, R46: NP; R_0603_1608Metric
R47: 120K; R_0402_1005Metric
U1: SC600YNAPAE53UGADA; XCVR_SC600YNAPAE53UGADA
U2, U3, U4, U5, U7: TPD2EUSB30; Texas_DRT-3
U6: PI3DBS12412A; CONV_MAX15035ETL+
U8: MPU-9250; InvenSense_QFN-24_3x3mm_P0.4mm

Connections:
/1.8V_GPIO: R2.1, U1.9
/1.8V_LCD: C24.1, C29.1, J7.19, J11.19, R12.1, R13.1, R14.1, R15.1, U1.10
/2.8V_SENSE: C25.1, C26.1, C30.1, C31.1, J8.1, J12.1, U1.11
/2.85V_LCD: C22.1, C23.1, C27.1, C28.1, J7.20, J11.20, U1.12
/ALS_INT_N: J20.2, R25.2, U1.177
/ANT_DRX: C33.2, R17.2, U1.149
/ANT_GNSS: C38.2, R19.2, U1.134
/ANT_MAIN: C32.2, R16.2, U1.19
/ANT_WIFI: C36.2, R18.2, U1.129
/BAT_PLUS: C9.1, C10.1, C11.1, C12.1, C13.1, C14.1, C16.1, U1.27, U1.36, U1.37, U1.38
/Cameras/AF_VDO: C67.1, C68.1, C69.1, C70.1, C76.1, C78.1, J17.2, J18.2, J19.2
/Cameras/AVDD: C63.1, C64.1, C65.1, C66.1, C72.1, C74.1, J17.7, J18.7, J19.7
/Cameras/DOVDD: C55.1, C56.1, C57.1, C58.1, C71.1, C73.1, J17.4, J18.4, J19.4
/Cameras/DVDD: C59.1, C60.1, C61.1, C62.1, C75.1, C77.1, J17.3, J18.3, J19.3
/DCAM_MCLK: J19.14, U1.194
/DCAM_PWDN: J19.12, U1.181
/DCAM_RESET: J19.11, U1.180
/EAR_N: C87.2, C88.1, LS1.2, U1.52
/EAR_P: C86.2, C87.1, LS1.1, U1.53
/FRONT_MCLK: J17.14, U1.100
/FRONT_PWDN: J17.12, U1.71
/FRONT_RESET: J17.11, U1.72
/FSYNC: R29.2, U1.237
/GYRO_INT: U1.178, U8.12
/LCD0_ID: J7.21, U1.153
/LCD0_TE: J7.18, U1.126
/LCD1_ID: J11.21, U1.151
/LCD1_RST: J11.17, U1.113
/LCD1_TE: J11.18, U1.114
/LCDO_RST: J7.17, U1.127
/LCD_BL_A: J7.24, J11.24, U1.21
/LCD_BL_K1: J7.23, U1.22
/LCD_BL_K2: J11.23, U1.23
/LDO12: R42.2, R43.2, R44.2, R45.2, R46.2, U1.179
/MIC1_N: J21.2, R30.2, R32.1, R32.2, U1.45
/MIC1_P: C84.1, J21.1, R31.1, R31.2, U1.44
/MIC3_P: C83.1, MK1.1, R33.1, R33.2, U1.169
/MIC_BIAS: C85.1, J21.3, MK1.5, R34.1, R34.2, U1.167
/PWR_KEY: R22.1, U1.39
/REAR_MCLK: J18.14, U1.99
/REAR_PWDN: J18.12, U1.73
/REAR_RESET: J18.11, U1.74
/SD_CLK: R37.2, U1.70
/SD_CMD: R40.2, U1.69
/SD_DATA0: R39.2, U1.68
/SD_DATA1: R41.2, U1.67
/SD_DATA2: R36.2, U1.66
/SD_DATA3: R38.2, U1.65
/SD_DET: D27.8, J22.9, J22.10, R47.1, U1.64
/SD_LD011: R48.2, U1.63
/SIM2_VDD: C7.2, D3.5, J2.1, R10.1, U1.210
/SIM_VDD: C3.2, D2.5, J1.1, R6.1, U1.141
/SPK_N: C90.2, C91.1, LS2.2, U1.54
/SPK_P: C89.2, C90.1, LS2.1, U1.55
/Sensors/LDO6_1V8: C80.1, R25.1, R28.1, U8.8, U8.22
/Sensors/LDO10_2V8: C81.1, J20.8, U8.13
/Sensors/SCL: J20.7, U8.23
/Sensors/SDA: J20.1, U8.24
/Sensors/VPH_PWR: C79.1, J20.5
/TP0_I2C_SCL: J8.6, R13.2, U1.140
/TP0_I2C_SDA: J8.5, R12.2, U1.206
/TP0_INT: J8.3, U1.139
/TP0_RST: J8.4, U1.138
/TP1_I2C_SCL: J12.6, R15.2, U1.205
/TP1_I2C_SDA: J12.5, R14.2, U1.204
/TP1_INT: J12.3, U1.137
/TP1_RST: J12.4, U1.136
/USB/RX+: C42.2, U6.4
/USB/RX-: C45.2, U6.5
/USB/RX_CON_1+: C49.2, U3.1
/USB/RX_CON_1-: C52.2, U3.2
/USB/RX_CON_2+: C53.2, U2.1
/USB/RX_CON_2-: C48.2, U2.2
/USB/TX+: C43.2, U6.1
/USB/TX-: C46.2, U6.2
/USB/TX_CON_1+: C51.2, U4.1
/USB/TX_CON_1-: C54.2, U4.2
/USB/TX_CON_2+: C47.2, U5.1
/USB/TX_CON_2-: C50.2, U5.2
/USB_CC1: J16.A5, U1.223
/USB_CC2: J16.B5, U1.224
/USB_D+: J16.A6, J16.B6, U1.32, U7.1
/USB_D-: J16.A7, J16.B7, U1.33, U7.2
/USB_SS_RX_M: C45.1, U1.172
/USB_SS_RX_P: C42.1, U1.171
/USB_SS_TX_M: C46.1, U1.175
/USB_SS_TX_P: C43.1, U1.174
/USIM1_CLK: R4.2, U1.143
/USIM1_DATA: R5.2, U1.142
/USIM1_DET: D2.6, J1.6, R2.2, U1.145
/USIM1_RST: R3.2, U1.144
/USIM2_CLK: R8.2, U1.208
/USIM2_DATA: R9.2, U1.209
/USIM2_RST: R7.2, U1.207
/VDD_RF: C19.1, C20.1, C21.1, U1.1, U1.2
/VOL_DOWN: R20.1, U1.147
/VOL_UP: R21.1, U1.146
/VPH_PWR: C15.1, C17.1, C18.1, U1.220, U1.221
/VRTC: BT1.1, U1.16
GND: BT1.2, C1.1, C2.1, C3.1, C4.2, C5.1, C6.1, C7.1, C8.2, C9.2, C10.2, C11.2, C12.2, C13.2, C14.2, C15.2, C16.2, C17.2, C18.2, C19.2, C20.2, C21.2, C22.2, C23.2, C24.2, C25.2, C26.2, C27.2, C28.2, C29.2, C30.2, C31.2, C32.1, C33.1, C34.1, C35.1, C36.1, C37.1, C38.1, C39.1, C41.1, C44.1, C55.2, C56.2, C57.2, C58.2, C59.2, C60.2, C61.2, C62.2, C63.2, C64.2, C65.2, C66.2, C67.2, C68.2, C69.2, C70.2, C71.2, C72.2, C73.2, C74.2, C75.2, C76.2, C77.2, C78.2, C79.2, C80.2, C81.2, C82.2, C83.2, C84.2, C85.2, C86.1, C88.2, C89.1, C91.2, C92.2, C93.2, C94.2, C95.2, C96.2, C97.2, C98.2, C99.2, D2.2, D3.2, D17.2, D18.2, D19.2, D20.2, D27.3, J1.5, J2.5, J7.1, J7.4, J7.7, J7.10, J7.13, J7.16, J7.S1, J7.S2, J8.2, J11.1, J11.4, J11.7, J11.10, J11.13, J11.16, J11.S1, J11.S2, J12.2, J16.A1, J16.A12, J16.B1, J16.B12, J16.S1, J17.6, J17.8, J17.13, J17.15, J17.18, J17.21, J17.24, J17.27, J17.30, J17.S1, J17.S2, J18.6, J18.8, J18.13, J18.15, J18.18, J18.21, J18.24, J18.27, J18.30, J18.S1, J18.S2, J19.6, J19.8, J19.13, J19.15, J19.18, J19.21, J19.24, J19.27, J19.30, J19.S1, J19.S2, J20.6, J21.4, J22.6, MK1.2, MK1.3, MK1.4, R1.2, R11.2, R24.1, R26.2, R27.1, R30.1, R35.1, R35.2, U1.3, U1.4, U1.18, U1.20, U1.28, U1.31, U1.34, U1.35, U1.40, U1.41, U1.42, U1.43, U1.47, U1.56, U1.62, U1.87, U1.98, U1.101, U1.112, U1.125, U1.128, U1.130, U1.133, U1.135, U1.148, U1.150, U1.154, U1.155, U1.156, U1.157, U1.158, U1.159, U1.163, U1.164, U1.165, U1.166, U1.168, U1.170, U1.173, U1.176, U1.182, U1.193, U1.195, U1.212, U1.213, U1.214, U1.218, U1.219, U1.222, U1.225, U1.235, U1.239, U1.240, U1.243, U1.245, U1.246, U1.247, U1.248, U1.249, U1.250, U1.251, U1.252, U1.253, U1.254, U1.255, U1.256, U1.257, U1.258, U1.259, U1.260, U1.261, U1.262, U1.263, U1.264, U1.265, U1.266, U1.267, U1.268, U1.269, U1.270, U1.271, U1.272, U1.273, U1.274, U1.275, U1.276, U1.277, U1.278, U1.279, U1.280, U1.281, U1.282, U1.283, U1.284, U1.285, U1.286, U1.287, U1.288, U1.289, U1.290, U1.291, U1.292, U1.293, U1.294, U1.295, U1.296, U1.297, U1.298, U1.299, U1.300, U1.301, U1.302, U1.303, U1.304, U1.305, U1.306, U1.307, U1.308, U1.309, U1.310, U1.311, U1.312, U1.313, U1.314, U1.315, U1.316, U1.317, U1.318, U1.319, U1.320, U1.321, U1.322, U1.323, U2.3, U3.3, U4.3, U5.3, U6.3, U6.12, U6.19, U7.3, U8.1, U8.18, U8.20
unnamed: C34.2, R16.1
unnamed: C35.2, R17.1
unnamed: C37.2, R18.1
unnamed: C1.2, D2.1, J1.7, R5.1, R6.2
unnamed: C2.2, D2.3, J1.3, R4.1
unnamed: C4.1, D2.4, J1.2, R3.1
unnamed: C5.2, D3.1, J2.7, R9.1, R10.2
unnamed: C6.2, D3.3, J2.3, R8.1
unnamed: C8.1, D3.4, J2.2, R7.1
unnamed: C39.2, C40.1, R19.1
unnamed: C41.2, C44.2, U6.7, U6.18
unnamed: C47.1, U6.16
unnamed: C48.1, U6.13
unnamed: C49.1, U6.9
unnamed: C50.1, U6.15
unnamed: C51.1, U6.11
unnamed: C52.1, U6.8
unnamed: C53.1, U6.14
unnamed: C54.1, U6.10
unnamed: C82.1, U8.10
unnamed: C92.1, D27.1, J22.1, R36.1, R42.1
unnamed: C93.1, D27.2, J22.2, R38.1, R43.1
unnamed: C94.1, D27.4, J22.3, R40.1, R44.1
unnamed: C95.1, D27.5, J22.5, R37.1
unnamed: C96.1, D27.6, J22.7, R39.1, R45.1
unnamed: C97.1, D27.7, J22.8, R41.1, R46.1
unnamed: C98.1, C99.1, D27.9, J22.4, R48.1
unnamed: D3.6, J2.6
unnamed: D17.1, R20.2
unnamed: D18.1, R21.2
unnamed: D19.1, R22.2
unnamed: J20.3, R26.1
unnamed: R27.2, R28.2, U8.9
unnamed: R29.1, U8.11
USB_VBUS: J16.A4, J16.A9, J16.B4, J16.B9, U1.162

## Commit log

2022-09-02 modified: README.md new file: src/0x0A/0x0A-cache.lib new file: src/0x0A/0x0A.kicad_pcb new file: src/0x0A/0x0A.pro new file: src/0x0A/0x0A.sch new file: src/0x0A/antenna.sch new file: src/0x0A/audio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
    [0x0A.kicad_pcb, 0x0A.sch, antenna.sch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]
2022-09-02 modified: src/0x0A/0x0A-cache.lib modified: src/0x0A/0x0A.sch modified: src/0x0A/antenna.sch modified: src/0x0A/audio.sch modified: src/0x0A/buttons.sch modified: src/0x0A/display.sch modified: src/0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
    [0x0A.sch, antenna.sch, audio.sch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]
2022-09-02 new file: imgs/better.png modified: src/0x0A/0x0A-cache.lib modified: src/0x0A/0x0A.sch modified: src/0x0A/antenna.sch modified: src/0x0A/audio.sch modified: src/0x0A/buttons.sch new file: src/0x0A/c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
    Added 3D models, integrated front & rear cameras, flash light, reformatting & more
    [0x0A.sch, antenna.sch, audio.sch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]
2022-09-04 Updated schematics, started working on board layout
    [0x0A.kicad_pcb, 0x0A.sch, antenna.sch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]
2022-09-04 new file: docs/schematics.pdf modified: src/0x0A/0x0A.pro Added schematics pdf file
